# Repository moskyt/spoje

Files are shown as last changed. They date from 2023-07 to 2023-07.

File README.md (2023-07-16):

# Spoje

## Hardware

### Napajeni

vsechna ctyri napeti maji svoji indikaci na prednim panelu a svuj vypinac

na vstupnich 230VAC je pojistka

POZOR! IEC konektor na vstupu nema standardizovane zapojeni, resp. ruzne kabely jsou ruzne. je tedy treba mit na pameti, ze L a N mohou byt prohozene (a nikdo s tim nic neudela)

### DC

Meanwell RD-35B (+5/+24V)

5V napaji arduino

24V napaji telefonni linku

### Trafo

pouziva se pro vyzvaneci AC

je to trafo 400->110, tedy 230->63 voltu, coz je optimalni

### Zapojeni

viz `spoje_pcb` -- projekt v kicadu

v 'doc/` je vyexportovane schema a PCB v kicadu

vsechny draty jsou popsane

## Ovladani

### Vypinace

napajeni ctyr napeti (master 230VAC, vyzvaneci trafo, dva vystupy z DC zdroje)

cervene reset tlacitko (hardware reset na RESET pinu)

### Zvoneni

zluta tlacitka jsou na vyzvaneni na prislusnych linkach. je to SW zvoneni, aktivace stavu POKE.

## Literatura

specifikace vyzvanecich tonu:

https://www.ctu.cz/sites/default/files/obsah/clanky/navrh-sitoveho-planu-signalizace-verejnych-telekomunikacnich-siti-poskytujicich-verejne-dostupnou/soubory/priloha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

https://vyvoj.hw.cz/navrh-obvodu/rozhrani/telefonni-linky-v-cr-a-sr.html

https://www.ranecommercial.com/legacy/note150.html

http://home.zcu.cz/~vargaj/U%20S%20T/Telefonni%20pristroje.pdf

http://mcu.cz/news.php?extend.8
http://mcu.cz/images/newspost_images/00/26/00-26.pdf

https://forum.arduino.cc/t/intercom-using-two-old-dial-telephones/606457

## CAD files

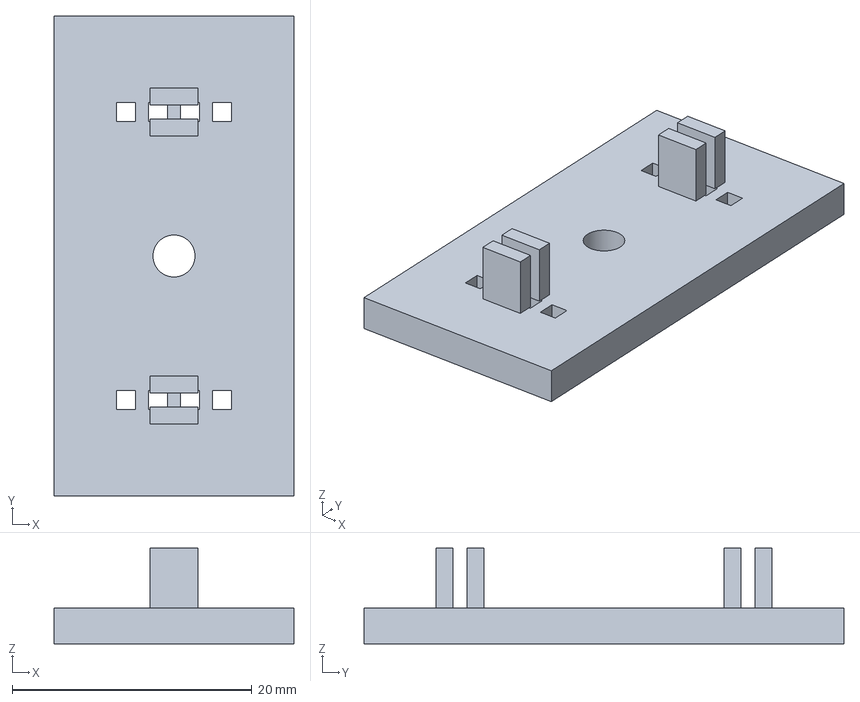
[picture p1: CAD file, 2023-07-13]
3d/neopixel_mount.3mf
20.0 x 40.0 x 8.00 mm

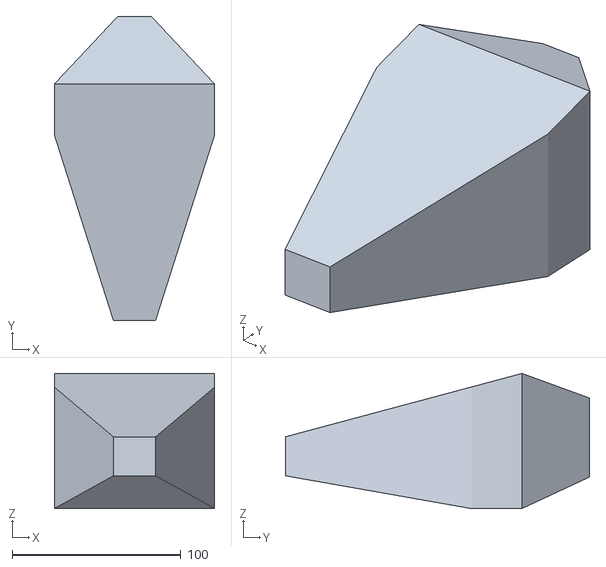
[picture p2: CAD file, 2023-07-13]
grafika/brean.stl
95.0 x 180.0 x 80.0

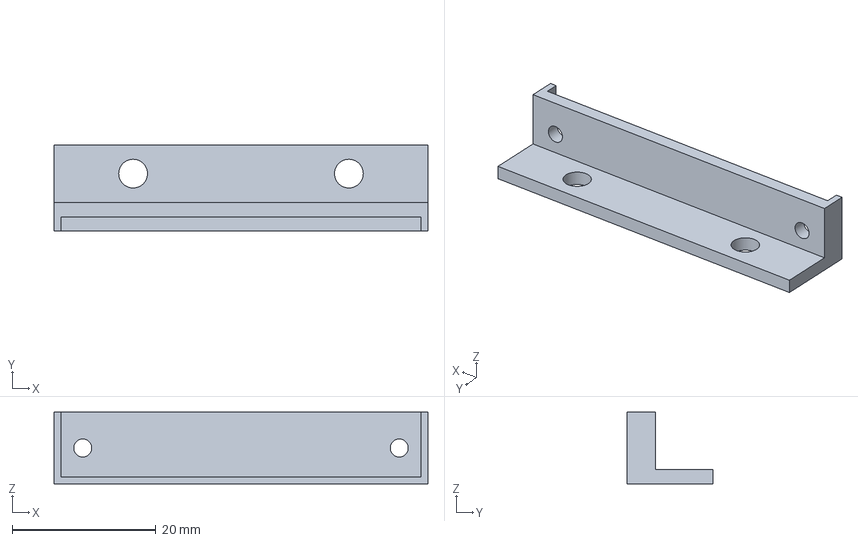
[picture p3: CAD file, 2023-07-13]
3d/relay_mount.3mf
52.0 x 12.0 x 10.0 mm

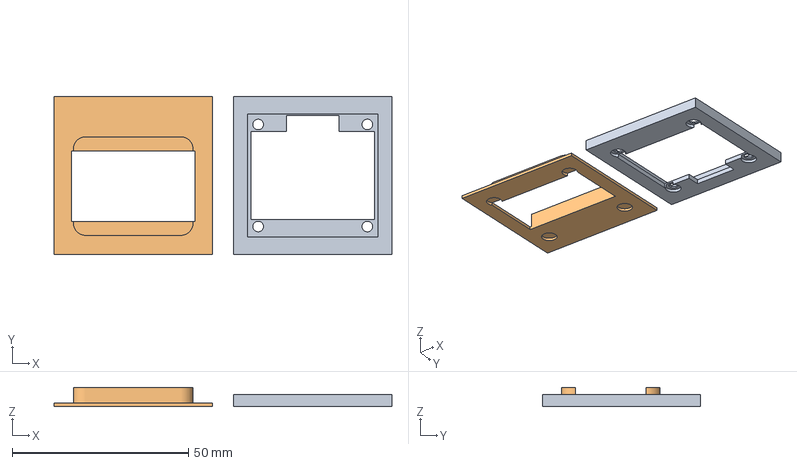
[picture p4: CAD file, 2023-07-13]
3d/oled_mount.3mf
96.0 x 45.0 x 5.50 mm
oled_mount.stl_1
oled_mount.stl_2

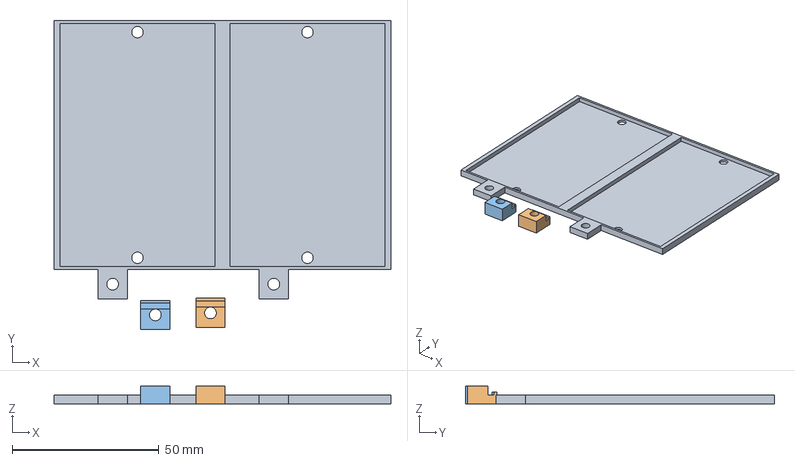
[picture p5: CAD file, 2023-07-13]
3d/boards_base.3mf
115.0 x 105.5 x 6.00 mm
boards_base.stl_1
boards_base.stl_2
boards_base.stl_3

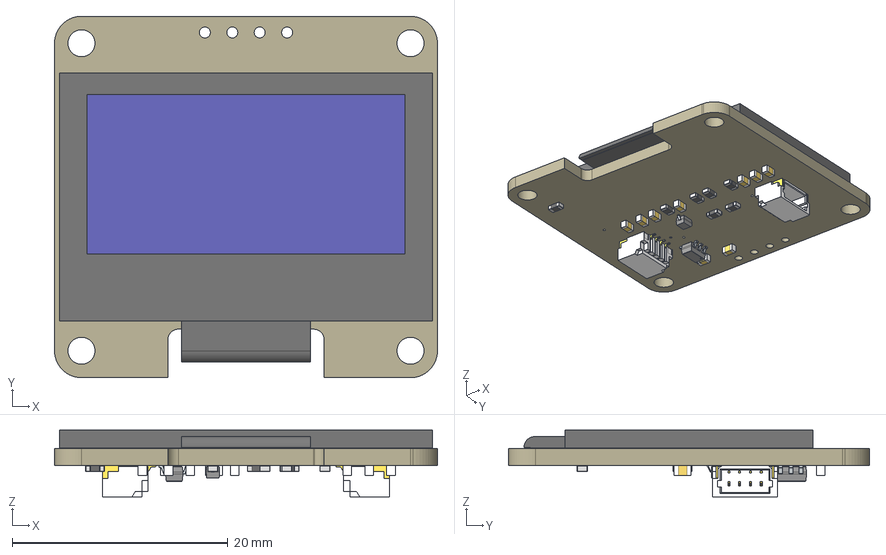
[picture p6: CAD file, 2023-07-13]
3d/OLED_1_3INCH_I2C.step
35.5 x 33.5 x 6.19 mm
Board
LASKAKIT_HEART_4MM
LASKKIT_10MM_SILKSCREEN
PinsArrayL
PinsArrayR
FilletPinL
FilletPinR
USUP_4MM_SILKSCREEN x 2
1X04_1MM_RA x 2
2,5-PAD x 4
C0603 x 9
R0603 x 7

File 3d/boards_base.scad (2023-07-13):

include <bosl2/std.scad>
$fn = 80;

eps = 0.01;


hole_spacing = 77;
board_x = 53;
board_spacing = 10;
board_y = 83;
board_z = 2;

hole_d = 3.9;

base_x = 115;
base_y = 85;
base_z = board_z + 1;

difference() {
    cuboid([base_x, base_y, base_z], anchor = TOP);
    
    up(eps)
    xcopies(board_spacing/2 + board_x, 2) {
        cuboid([board_x, board_y, board_z], anchor = TOP);
        ycopies(hole_spacing, 2)
        zcyl(d = hole_d, l = base_z+2*eps, anchor = TOP);
    }
}

fwd(base_y/2)
left(base_x/2) {
    right(20) {
        difference() {
            cuboid([10, 10, base_z], anchor = TOP+BACK);
            fwd(5) up(eps)
            zcyl(d = 4, l = base_z+2*eps, anchor = TOP);
        }
    }
    right(75) {
        difference() {
            cuboid([10, 10, base_z], anchor = TOP+BACK);
            fwd(5) up(eps)
            zcyl(d = 4, l = base_z+2*eps, anchor = TOP);
        }
    }
}


    right(100) {
        xcopies(20, 2)
        difference() {
            union() {
                cuboid([10, 10, 5], anchor = TOP+BACK);
                up(1)
                cuboid([10, 1, 5], anchor = TOP+BACK);
                fwd(3.75)
                up(5)
                cuboid([10, 6.25, 5], anchor = TOP+BACK);
            }
            fwd(5) up(eps)
            zcyl(d = 3.9, l = 100);
        }
    }

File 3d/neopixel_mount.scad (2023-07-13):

include <bosl2/std.scad>
$fn = 80;

eps = 0.01;

spacing = 24;

block_x = 20;
block_y = 40;
slit_x = 8;
slit_y = 0.8;
support_z = 5;

inner_z = 3;
outer_z = 3;

spacer_d = 10;

left(40)
difference() {
    cuboid([block_x, block_y, outer_z], anchor = BOTTOM);
    
    down(eps)
    ycopies(n = 2, l = spacing) 
    zcyl(l=100, d=spacer_d);
    
    zcyl(l=100, d=3.5);
    up(outer_z/2)
    zcyl(l=100, d=6, anchor = BOTTOM);
}

difference() {
    union() {
        cuboid([block_x, block_y, inner_z], anchor = BOTTOM);
        
        ycopies(n = 2, l = spacing) 
        up(inner_z)
        cuboid([slit_x/2, slit_x/2, support_z], anchor = BOTTOM);
    }
    
    ycopies(n = 2, l = spacing) {
        up(inner_z)
        cuboid([slit_x, slit_y*1.5, support_z+2*eps], anchor = BOTTOM);
        
        down(eps)
        xcopies(n = 4, l = slit_x) 
        cuboid([slit_y*2, slit_y*2, inner_z+2*eps], anchor = BOTTOM);
    }
    
    zcyl(l=100, d=3.5);
}

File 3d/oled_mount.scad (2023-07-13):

include <bosl2/std.scad>
$fn = 80;

eps = 0.01;

window_x = 34;
window_y = 28;
glass_x = 35;
glass_y = 25;
view_x = 35;
view_y = 20;
mount_x = 45;
mount_y = 45;
board_x = 37;
board_y = 35;

outer_z = 1.5;
inner_z = 2;

cover_z = 1;    
shift_window = 3;

back(100) 
union() {
difference() {
    cuboid([mount_x, mount_y, cover_z], anchor = BOTTOM);

    down(eps)
    back(shift_window)
    cuboid([view_x, view_y, cover_z+2*eps], anchor = BOTTOM);

    up(0.1)
    xcopies(n=2, l=31)
    ycopies(n=2, l=29)
    zcyl(d = 5, l = cover_z+2*eps, anchor=BOTTOM);

}
    back(shift_window) difference() {
        cuboid([window_x, window_y, 4.5], anchor = TOP, edges="Z", rounding=3.5);
        up(eps)
        cuboid([view_x, view_y, 4.5+2*eps], anchor = TOP);
    }

}

difference() {
    cuboid([mount_x, mount_y, outer_z+inner_z], anchor = BOTTOM);
    down(eps)
    cuboid([glass_x, glass_y, outer_z+inner_z+2*eps], anchor = BOTTOM);
    up(outer_z)
    cuboid([board_x, board_y, inner_z+2*eps], anchor = BOTTOM);

    down(eps)
    xcopies(n=2, l=31)
    ycopies(n=2, l=29)
    zcyl(d = 3, l = 8, anchor=BOTTOM);

    down(eps)
    xcopies(n=2, l=31)
    ycopies(n=2, l=29)
    zcyl(d = 5, l = outer_z-0.5, anchor=BOTTOM);
 
    down(eps)
    back(12)
    cuboid([15, 5, 100+2*eps], anchor = BOTTOM+FWD);
   
}

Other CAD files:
3d/relay_mount.scad
3d/boards_base.stl
3d/neopixel_mount.stl
3d/oled_mount.stl
3d/relay_mount.stl

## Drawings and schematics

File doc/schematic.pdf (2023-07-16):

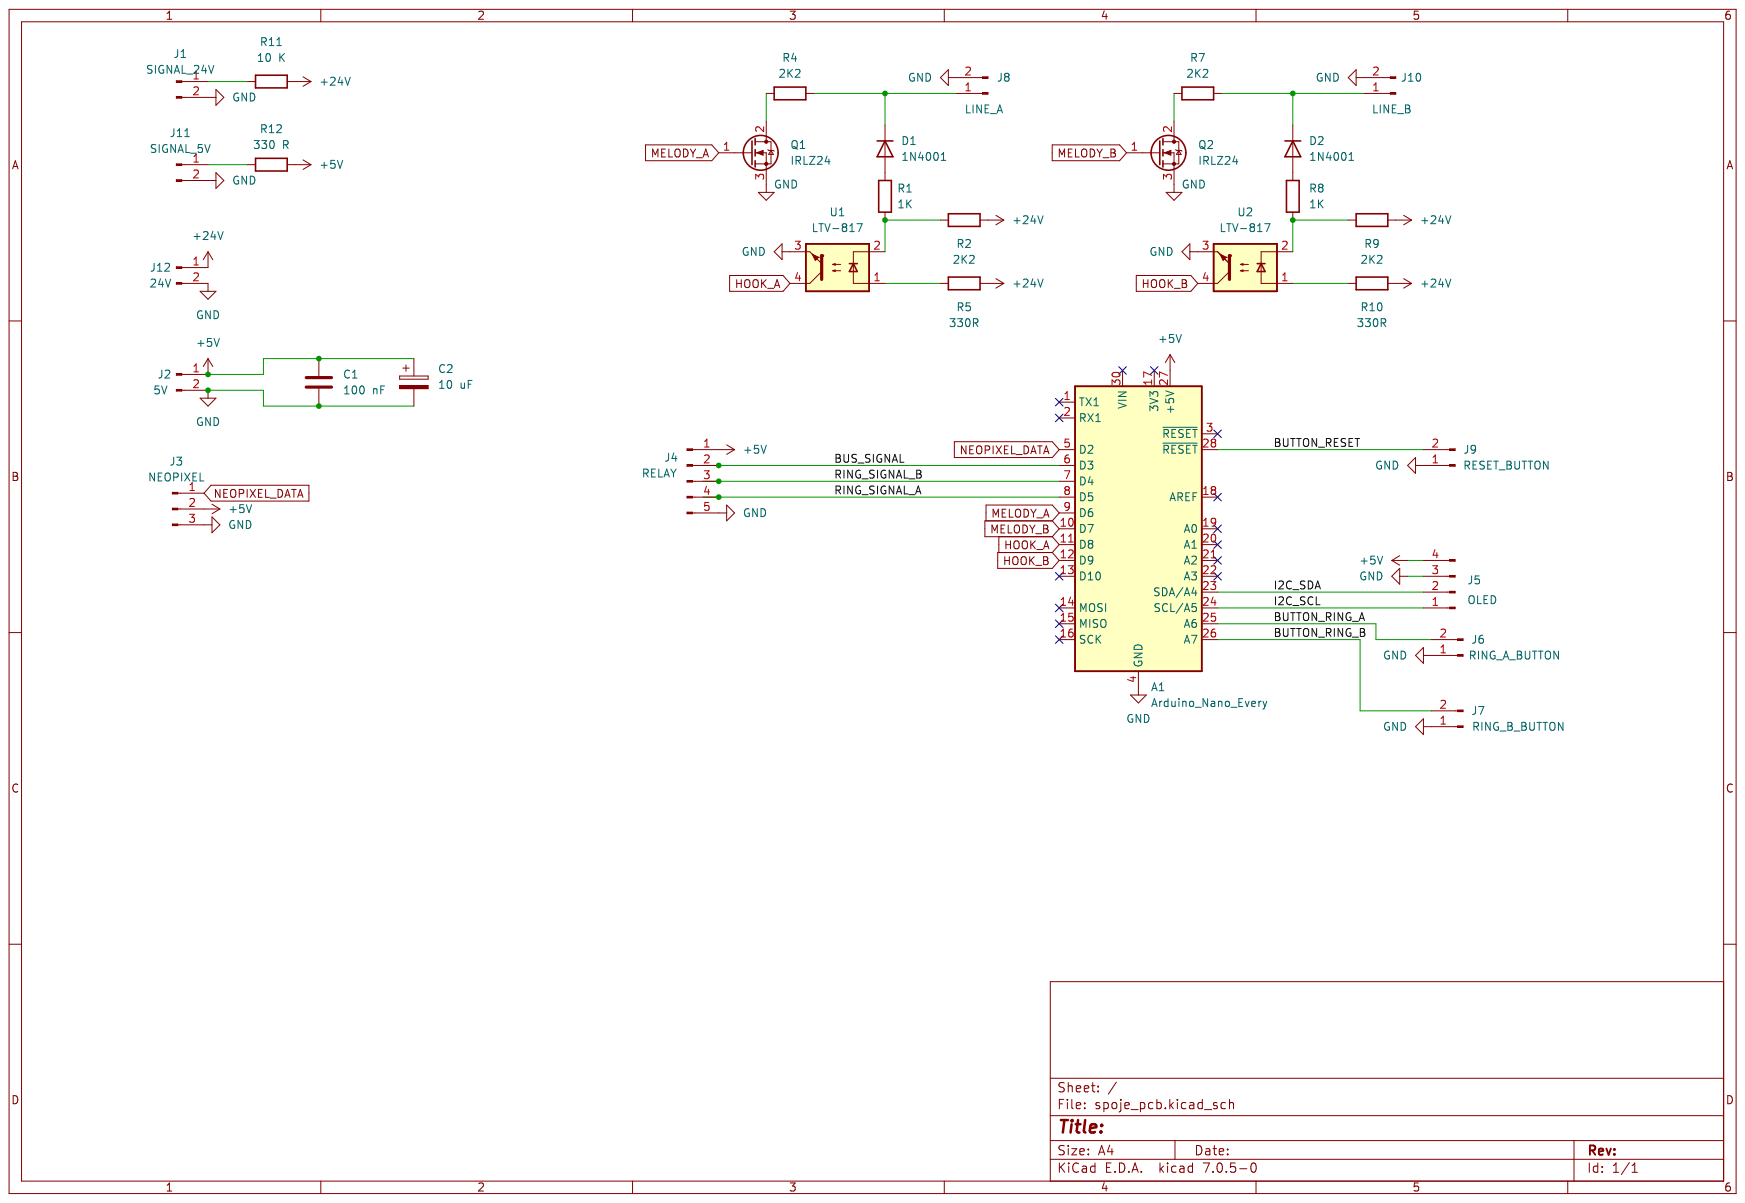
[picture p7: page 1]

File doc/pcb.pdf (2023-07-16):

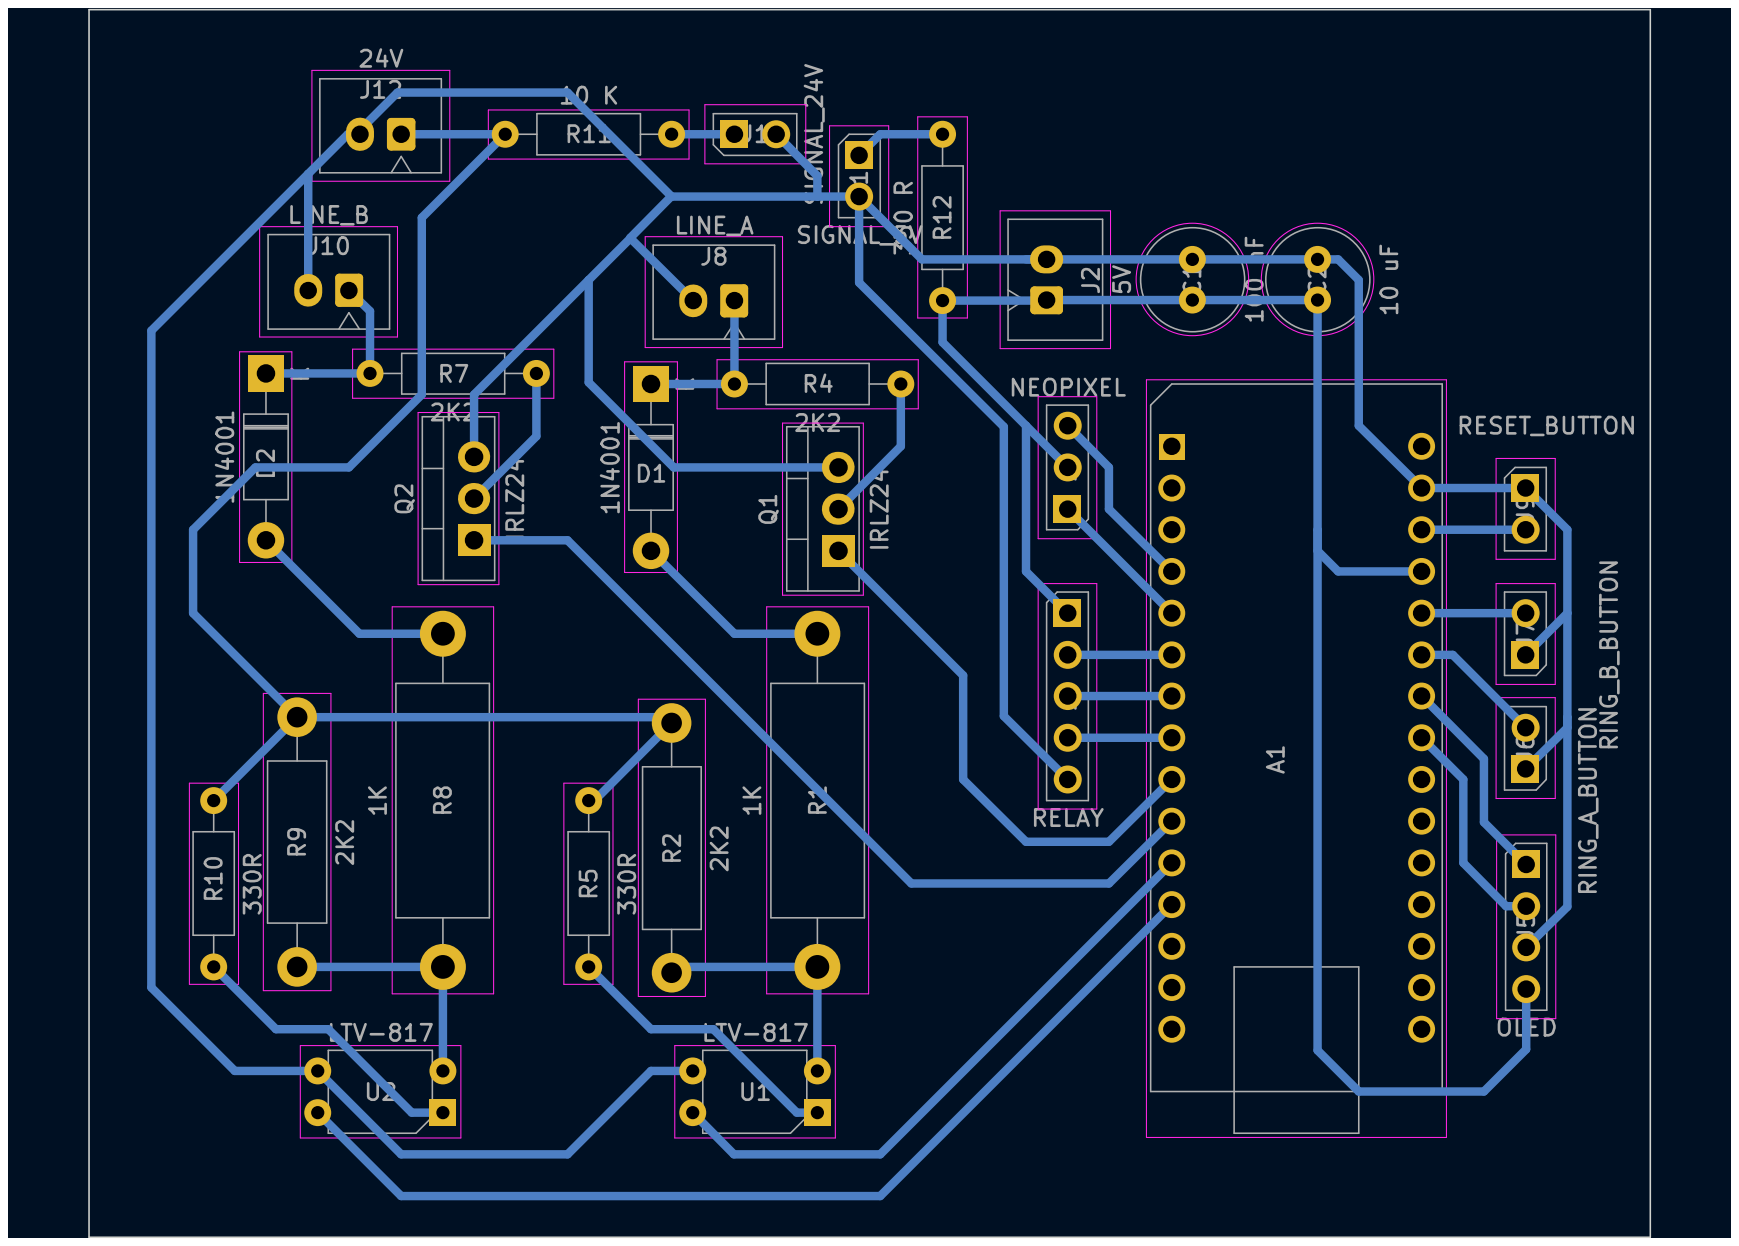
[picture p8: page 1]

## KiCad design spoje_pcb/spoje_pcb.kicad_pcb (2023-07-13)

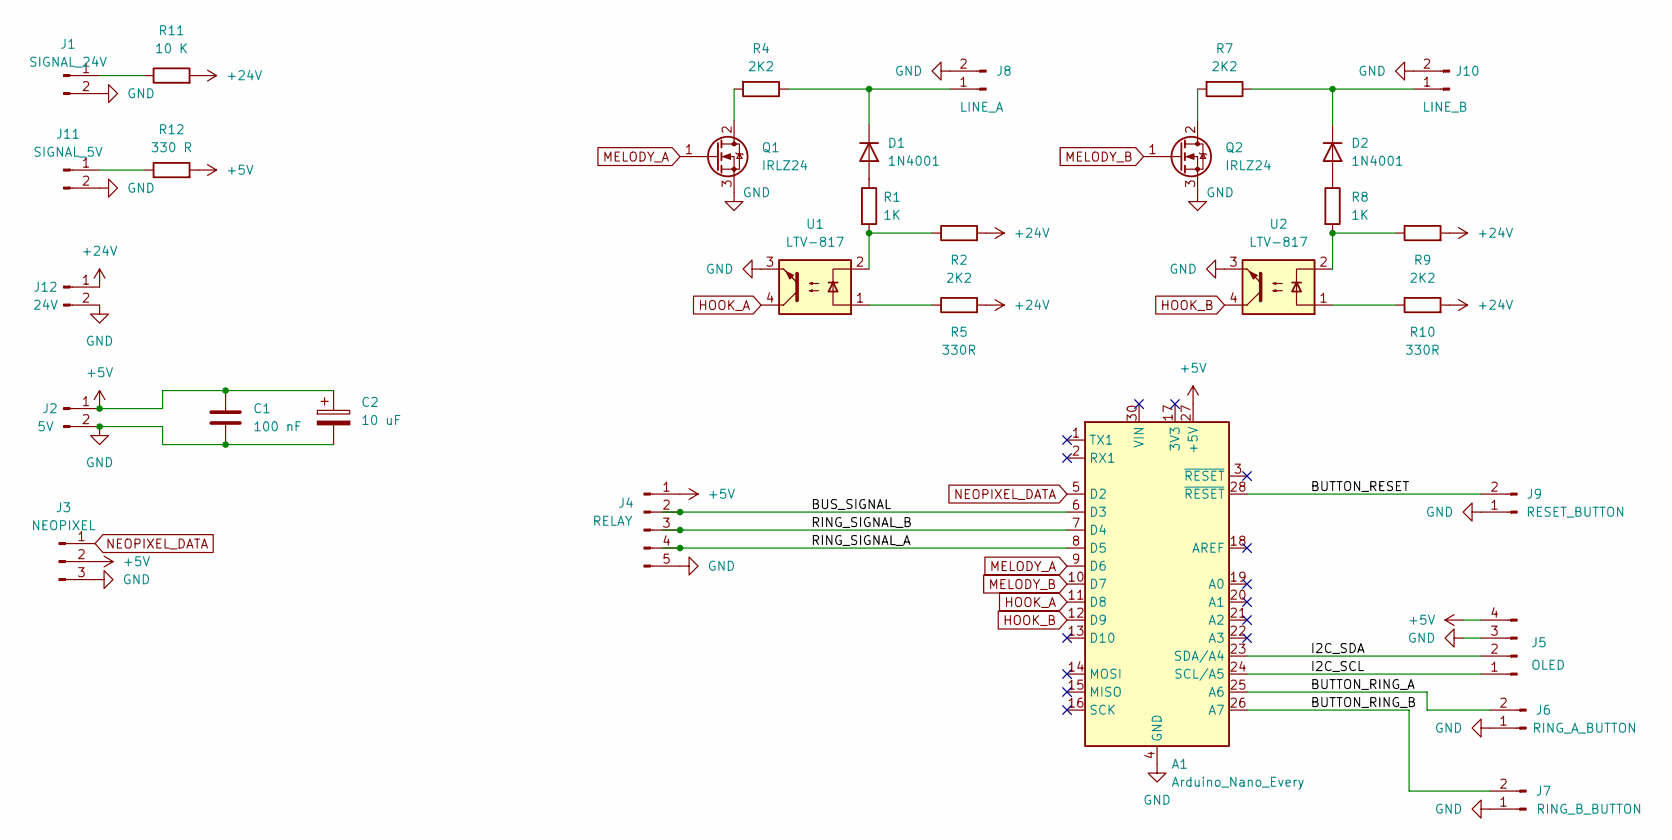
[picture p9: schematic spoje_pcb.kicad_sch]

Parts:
A1: Arduino_Nano_Every; Arduino_Nano
C1: 100 nF; C_Radial_D6.3mm_H5.0mm_P2.50mm
C2: 10 uF; C_Radial_D6.3mm_H5.0mm_P2.50mm
D1, D2: 1N4001; D_DO-41_SOD81_P10.16mm_Horizontal
J1: SIGNAL_24V; PinHeader_1x02_P2.54mm_Vertical
J2: 5V; JST_XH_B2B-XH-A_1x02_P2.50mm_Vertical
J3: NEOPIXEL; PinHeader_1x03_P2.54mm_Vertical
J4: RELAY; PinHeader_1x05_P2.54mm_Vertical
J5: OLED; PinHeader_1x04_P2.54mm_Vertical
J6: RING_A_BUTTON; PinHeader_1x02_P2.54mm_Vertical
J7: RING_B_BUTTON; PinHeader_1x02_P2.54mm_Vertical
J8: LINE_A; JST_XH_B2B-XH-A_1x02_P2.50mm_Vertical
J9: RESET_BUTTON; PinHeader_1x02_P2.54mm_Vertical
J10: LINE_B; JST_XH_B2B-XH-A_1x02_P2.50mm_Vertical
J11: SIGNAL_5V; PinHeader_1x02_P2.54mm_Vertical
J12: 24V; JST_XH_B2B-XH-A_1x02_P2.50mm_Vertical
Q1, Q2: IRLZ24; TO-220-3_Vertical
R1, R8: 1K; R_Axial_DIN0614_L14.3mm_D5.7mm_P20.32mm_Horizontal
R2, R9: 2K2; R_Axial_DIN0411_L9.9mm_D3.6mm_P15.24mm_Horizontal
R4, R7: 2K2; R_Axial_DIN0207_L6.3mm_D2.5mm_P10.16mm_Horizontal
R5, R10: 330R; R_Axial_DIN0207_L6.3mm_D2.5mm_P10.16mm_Horizontal
R11: 10 K; R_Axial_DIN0207_L6.3mm_D2.5mm_P10.16mm_Horizontal
R12: 330 R; R_Axial_DIN0207_L6.3mm_D2.5mm_P10.16mm_Horizontal
U1, U2: LTV-817; DIP-4_W7.62mm

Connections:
+5V: A1.27 (+5V), C1.1, C2.1, J2.1, J3.2, J4.1, J5.4, R12.2
+24V: J12.1, R2.2, R5.2, R9.2, R10.2, R11.2
/BUS_SIGNAL: A1.6 (D3), J4.2
/BUTTON_RESET: A1.28 (~RESET), J9.2
/BUTTON_RING_A: A1.25 (A6), J6.2
/BUTTON_RING_B: A1.26 (A7), J7.2
/I2C_SCL: A1.24 (SCL/A5), J5.1
/I2C_SDA: A1.23 (SDA/A4), J5.2
/RING_SIGNAL_A: A1.7 (D4), J4.3
/RING_SIGNAL_B: A1.8 (D5), J4.4
GND: A1.4 (GND), A1.29 (GND), C1.2, C2.2, J1.2, J2.2, J3.3, J4.5, J5.3, J6.1, J7.1, J8.2, J9.1, J10.2, J11.2, J12.2, Q1.3 (S), Q2.3 (S), U1.3, U2.3
HOOK_A: A1.11 (D8), U1.4
HOOK_B: A1.12 (D9), U2.4
MELODY_A: A1.9 (D6), Q1.1 (G)
MELODY_B: A1.10 (D7), Q2.1 (G)
NEOPIXEL_DATA: A1.5 (D2), J3.1
unnamed: D1.2 (A), R1.1
unnamed: D1.1 (K), J8.1, R4.1
unnamed: D2.2 (A), R8.1
unnamed: D2.1 (K), J10.1, R7.1
unnamed: J1.1, R11.1
unnamed: J11.1, R12.1
unnamed: Q1.2 (D), R4.2
unnamed: Q2.2 (D), R7.2
unnamed: R1.2, R2.1, U1.2
unnamed: R5.1, U1.1
unnamed: R8.2, R9.1, U2.2
unnamed: R10.1, U2.1

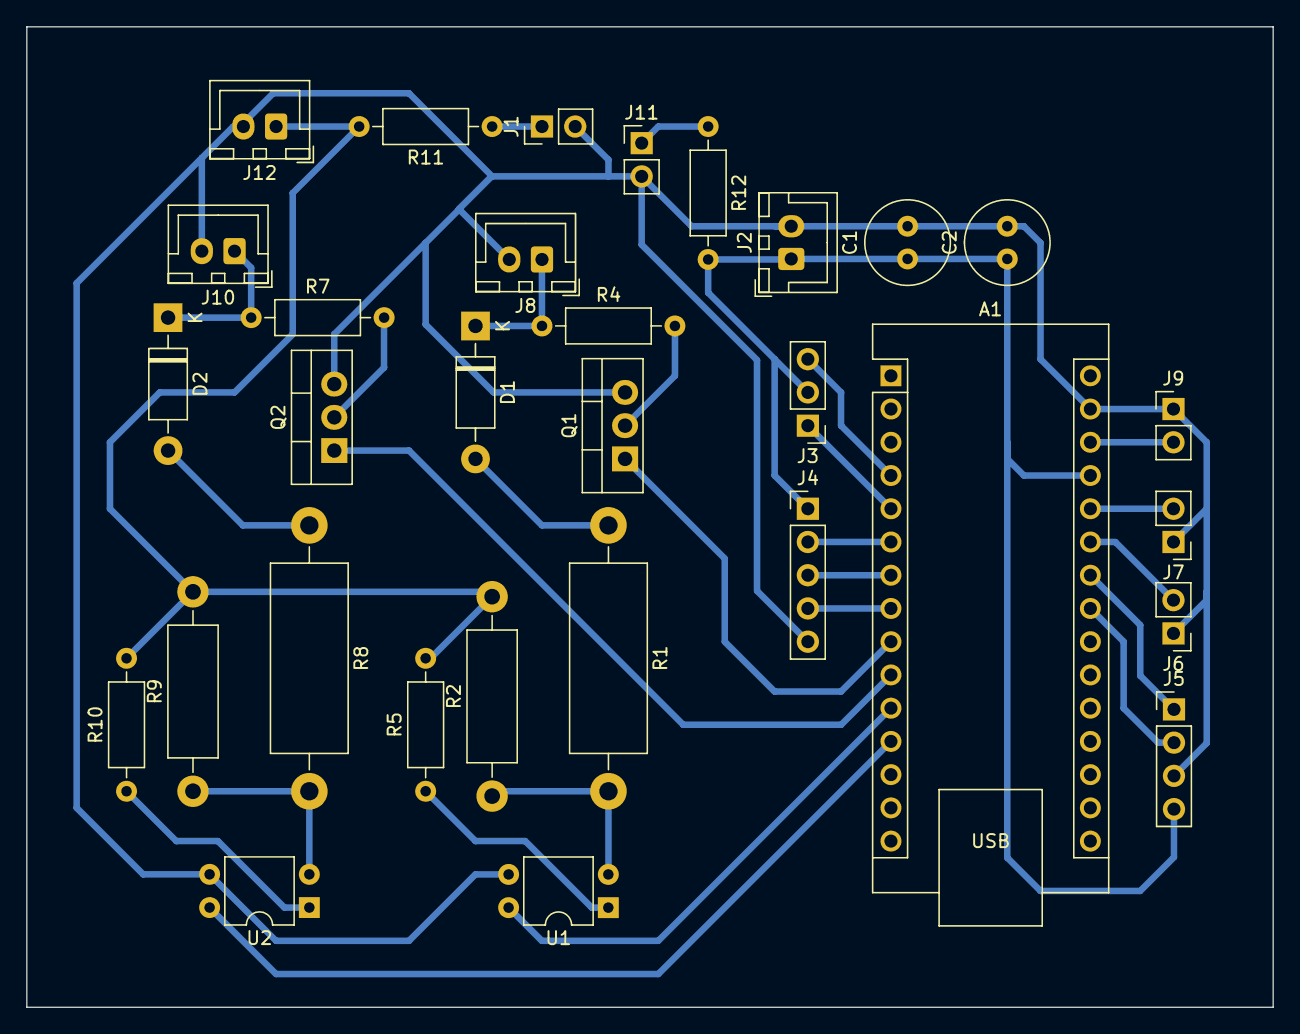
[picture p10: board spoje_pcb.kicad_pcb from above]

Board: 2 copper layers, 95.2 x 74.9 mm, 31 parts (0 on the bottom side), 28 nets.

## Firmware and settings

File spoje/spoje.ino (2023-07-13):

// #include "pcf8574.h" // pcf8574 library, 1.0.3
#include <Wire.h>
// #include <Adafruit_GFX.h> // Adafruit GFX library, 1.11.5
// #include <Adafruit_SH110X.h> // Adafruit SH110X library, 2.1.8
#include <Adafruit_NeoPixel.h> // Adafruit NeoPixel library, 1.11.0
#include <Toggle.h> // Toggle library, 3.1.8
#include <U8g2lib.h> // U8g2@2.33.15

const int PHONE_NUMBER_A = 111;
const int PHONE_NUMBER_B = 222;

//--- pins and adresses

const int PIN_HOOK_A = 8;
const int PIN_HOOK_B = 9;
const int PIN_NEOPIXEL = 2;
const int PIN_TONE_A = 6;
const int PIN_TONE_B = 7;
const int PIN_RING_A = 5;
const int PIN_RING_B = 4;
const int PIN_BUS = 3;
const int PIN_BUTTON_A = 20;
const int PIN_BUTTON_B = 21;

const int I2C_OLED = 0x3C;

//--- hardware

//Adafruit_SH1106G display(128, 64, &Wire, -1);
U8G2_SH1106_128X64_NONAME_1_HW_I2C display(U8G2_R0, U8X8_PIN_NONE);
U8G2LOG log_display;
#define U8LOG_WIDTH 25
#define U8LOG_HEIGHT 8
uint8_t log_buffer[U8LOG_WIDTH*U8LOG_HEIGHT];

Adafruit_NeoPixel pixels(2, PIN_NEOPIXEL, NEO_RGB + NEO_KHZ800);

// timers stuff -- taken from the library

// Select USING_16MHZ     == true for  16MHz to Timer TCBx => shorter timer, but better accuracy
// Select USING_8MHZ      == true for   8MHz to Timer TCBx => shorter timer, but better accuracy
// Select USING_250KHZ    == true for 250KHz to Timer TCBx => shorter timer, but better accuracy
// Not select for default 250KHz to Timer TCBx => longer timer,  but worse accuracy
#define USING_16MHZ     false
#define USING_8MHZ      false
#define USING_250KHZ    false

// Select the timers you're using
// Cannot use TIMER_1 as it conflicts with tone
// TIMER_3 also conflicts with something
#define USE_TIMER_0     false
#define USE_TIMER_1     false
#define USE_TIMER_2     true
#define USE_TIMER_3     false

#include "megaAVR_TimerInterrupt.h"
#include "megaAVR_ISR_Timer.h" 

ISR_Timer ISR_Timer2;
int timer_dial = -1;
int timer_ring = -1;
int timer_melody = -1;

// --- line modes
enum lineMode {
  MODE_NULL, // this is only for the 'new_mode', meaning no change
  MODE_IDLE, // no ringing, on hook
  MODE_WAIT, // off hook, but not dialing (play Dial melody)
  MODE_DIAL, // dialing in progress (no melody here)
  MODE_INVALID, // failed call, invalid number (play Invalid melody)
  MODE_BUSY, // failed call, other is busy (play Busy melody)
  MODE_CALL, // successful call, waiting for the other to pick up (play Ring melody)
  MODE_RING, // ringing
  MODE_CONNECT, // connected to the bus
  MODE_POKE, // quick ring notification
  MODE_MUTE // picked up but the other one is already active, so "play dead"
};

// --- lines
enum lineID { LINE_A, LINE_B };

volatile lineMode mode_A = MODE_IDLE;
volatile lineMode mode_B = MODE_IDLE;

volatile bool hw_ring_A = false;
volatile bool hw_ring_B = false;

// --- dial stuff --- this is ofcourse stupid, needs to be twice => class
// timer/counter
volatile int dialCount = 0;
// current number being read
volatile int dialBuffer = 0;
// number of digits in code
const int dialNMax = 3;
// current code read
volatile int dialNumber[dialNMax] = {0,0,0};
// current digit
volatile int dialPtr = 0;
//
volatile int dial_read = -1;
//
volatile int currentDialPin = -1;
//
volatile bool dialHangupFlag = false;
//
volatile bool dialStartedFlag = false;
//
volatile bool dialPrimerFlag = false;

// --- melodies: tone-duration pairs. last tone has to be 0.
// unit in CTU specs is 165 ms, we have 150 
const int melodyDialLength_ = 4;
unsigned short int melodyDial_[2*melodyDialLength_] = {1,2,0,2,1,4,0,4};
const int melodyCallLength_ = 2;
unsigned short int melodyCall_[2*melodyCallLength_] = {1,6,0,24};
const int melodyInvalidLength_ = 4;
unsigned short int melodyInvalid_[2*melodyInvalidLength_] = {2,2,3,2,4,2,0,10};
const int melodyBusyLength_ = 2;
unsigned short int melodyBusy_[2*melodyBusyLength_] = {1,2,0,2};
const int melodyFailedLength_ = 2;
unsigned short int melodyFailed_[2*melodyFailedLength_] = {1,1,0,1};

// length of current melody (in melodyBuffer)
int melodyLength = 0;
// pointer to current note in melodyBuffer
int melodyPointer = 0;
// pin on which the melody is played
int melodyPin = 0;
// current melody buffer (expanded melody vector)
int melodyBuffer[100];

// count cycles where both lines are idle
int idleCounter = 0;
// at this count system goes to sleep
const int idleThreshold = 1000;
// sleep flag
bool sleep = false;

// handle for the slow ISR interrrupts (ring and melody)
void Timer2Handler() {
  ISR_Timer2.run();
}

// this is kinda melodyPonter
volatile int ringCounter = 0;

void RingHandler() {
  if ((mode_A == MODE_RING) || (mode_B == MODE_RING)) {
    // this looks like a good pattern:
    // ---.---.....
    if (
        (ringCounter >= 0 && ringCounter < 3 ) ||
        (ringCounter >= 4 && ringCounter < 7 )
      ) {
      if (mode_A == MODE_RING) hw_ring_A = true;
      if (mode_B == MODE_RING) hw_ring_B = true;
    } else {
      hw_ring_A = false;
      hw_ring_B = false;
    }
    ringCounter++;
    if (ringCounter >= 12) ringCounter = 0;
  } else if ((mode_A == MODE_POKE) || (mode_B == MODE_POKE)) {
    if (
        (ringCounter >=  0 && ringCounter <  2 ) ||
        (ringCounter >=  4 && ringCounter <  6 ) ||
        (ringCounter >=  8 && ringCounter < 10 ) ||
        (ringCounter >= 12 && ringCounter < 14 ) ||
        (ringCounter >= 16 && ringCounter < 18 )
      ) {
      if (mode_A == MODE_POKE) hw_ring_A = true;
      if (mode_B == MODE_POKE) hw_ring_B = true;
    } else {
      hw_ring_A = false;
      hw_ring_B = false;
    }
    ringCounter++;
    if (ringCounter >= 20) {
      ringCounter = 0;
      if (mode_A == MODE_POKE) {
        Serial.println("A => IDLE");
        mode_A = MODE_IDLE;
      }
      if (mode_B == MODE_POKE) {
        Serial.println("B => IDLE");
        mode_B = MODE_IDLE;
      }
    }
  } else {
    hw_ring_A = false;
    hw_ring_B = false;
    ringCounter = 0;
  }
}

// byte hook_A_ = LOW;
// byte hook_B_ = LOW;
volatile Toggle hook_A(PIN_HOOK_A);
volatile Toggle hook_B(PIN_HOOK_B);
Toggle *dialer = NULL;

Toggle ring_button_A(PIN_BUTTON_A);
Toggle ring_button_B(PIN_BUTTON_B);

const int hook_state_threshold = 100;
const int hook_pickup_threshold = 150;
//const int hook_state_threshold = 500;
//const int hook_pickup_threshold = 750;
bool off_hook_A = false;
bool off_hook_B = false;

void setStatus(lineMode mode, int pixel_index) {
  if (mode == MODE_IDLE)
    pixels.setPixelColor(pixel_index, 10, 10, 10);
  else if (mode == MODE_WAIT)
    pixels.setPixelColor(pixel_index,  0, 50,  0);
  else if (mode == MODE_DIAL)
    pixels.setPixelColor(pixel_index,  0, 90,  0);
  else if (mode == MODE_INVALID)
    pixels.setPixelColor(pixel_index, 50, 50,  0);
  else if (mode == MODE_BUSY)
    pixels.setPixelColor(pixel_index, 50, 20,  0);
  else if (mode == MODE_CALL)
    pixels.setPixelColor(pixel_index,  0, 50, 50);
  else if (mode == MODE_RING)
    pixels.setPixelColor(pixel_index, 50,  0, 50);
  else if (mode == MODE_POKE)
    pixels.setPixelColor(pixel_index,250,  0,250);
  else if (mode == MODE_CONNECT)
    pixels.setPixelColor(pixel_index,  0,  0, 50);
  else
    pixels.setPixelColor(pixel_index,  1,  1,  1);
}

void loop() {

  if (currentDialPin == PIN_HOOK_A) {
    if (dialHangupFlag) {
      stopMelody();
      off_hook_A = false; 
      currentDialPin = -1;
      ISR_Timer2.disable(timer_dial);
      hook_A.clearTimer();
      hook_A.poll();
    } else {
      off_hook_A = true;
    }
  } else {
    hook_A.poll();

    if (hook_A.releasedFor(hook_pickup_threshold)) off_hook_A = true;
    if (hook_A.pressedFor(hook_state_threshold))  off_hook_A = false;
  }

  if (currentDialPin == PIN_HOOK_B) {
    if (dialHangupFlag) {
      stopMelody();
      off_hook_B = false; 
      currentDialPin = -1;
      ISR_Timer2.disable(timer_dial);
      hook_B.clearTimer();
      hook_B.poll();
    } else {
      off_hook_B = true;
    }
  } else {
    hook_B.poll();

    if (hook_B.releasedFor(hook_pickup_threshold)) off_hook_B = true;
    if (hook_B.pressedFor(hook_state_threshold))  off_hook_B = false;
  }

  if (hw_ring_A) off_hook_A = false;
  if (hw_ring_B) off_hook_B = false;

  unsigned long now = millis();
  
  // Serial.print(off_hook_A);
  // Serial.print(off_hook_B);
  // Serial.print("-");
  // Serial.print(digitalRead(PIN_HOOK_A));
  // Serial.println(digitalRead(PIN_HOOK_B));

  {
    lineMode new_mode = updateState(LINE_A, mode_A, off_hook_A, 'A', mode_B);  
    if (new_mode != MODE_NULL) {
      mode_A = new_mode;
      if (new_mode == MODE_WAIT) {
        log_display.println("A zvednul sluchatko");
      }
      setNewState(LINE_A, new_mode, 'A');
    }
    if (new_mode == MODE_WAIT) {
      currentDialPin = PIN_HOOK_A;
      dialCount = 0;
      dialHangupFlag = false;
      dialStartedFlag = false;
      dialPrimerFlag = false;
      dialer = &hook_A;
      digitalWrite(PIN_TONE_A, LOW);
      dialer->poll();
      delay(1);
      ISR_Timer2.enable(timer_dial);
    }
    if (new_mode == MODE_DIAL) {
      stopMelody();
    }
  }
  {
    lineMode new_mode = updateState(LINE_B, mode_B, off_hook_B, 'B', mode_A);  
    if (new_mode != MODE_NULL) {
      mode_B = new_mode;
      if (new_mode == MODE_WAIT) {
        log_display.println("B zvednul sluchatko");
      }
      setNewState(LINE_B, new_mode, 'B');
    }
    if (new_mode == MODE_WAIT) {
      currentDialPin = PIN_HOOK_B;
      dialCount = 0;
      dialHangupFlag = false;
      dialStartedFlag = false;
      dialPrimerFlag = false;
      dialer = &hook_B;
      pinMode(currentDialPin, INPUT_PULLUP);
      digitalWrite(PIN_TONE_B, LOW);
      dialer->poll();
      delay(1);
      ISR_Timer2.enable(timer_dial);
    }
    if (new_mode == MODE_DIAL) {
      stopMelody();
    }
  }

  ring_button_A.poll();
  ring_button_B.poll();
  if ((mode_A == MODE_IDLE) && (mode_B == MODE_IDLE)) {
    if (ring_button_A.onPress()) {
      Serial.println(F("A ~ POKE"));
      mode_A = MODE_POKE;
    }
    if (ring_button_B.onPress()) {
      Serial.println(F("B ~ POKE"));
      mode_B = MODE_POKE;
    }
  }

  // -- did someone finish dialing?
  if (dial_read >= 0) {
    currentDialPin = 0;
    ISR_Timer2.disable(timer_dial);

    if (mode_A == MODE_DIAL) 
      mode_A = processDial(LINE_A, 'A', 'B', PHONE_NUMBER_B);
    if (mode_B == MODE_DIAL) 
      mode_B = processDial(LINE_B, 'B', 'A', PHONE_NUMBER_A);

    dial_read = -1;
  }

  // -- now either ring or switch to busy
  executeRing(LINE_A, LINE_B, mode_A, mode_B, 'A', 'B');
  executeRing(LINE_B, LINE_A, mode_B, mode_A, 'B', 'A');


  // -- AWFUL HACK! lets disable it for a while it might make things baad
  // if (mode_A == MODE_WAIT && mode_B == MODE_IDLE) melodyPin = PIN_TONE_A;
  //if (mode_B == MODE_WAIT && mode_A == MODE_IDLE) melodyPin = PIN_TONE_B;

  // -- connect
  if ((mode_A == MODE_CONNECT && mode_B == MODE_CALL) || (mode_A == MODE_CALL && mode_B == MODE_CONNECT)) {
    Serial.println("Connecting!");
    log_display.println("Spojuji hovor");

    stopMelody();
    currentDialPin = 0;
    ISR_Timer2.disable(timer_dial);
    setNewState(LINE_A, MODE_CONNECT, 'A');
    setNewState(LINE_B, MODE_CONNECT, 'B');
    mode_A = MODE_CONNECT;    
    mode_B = MODE_CONNECT;    
  }

  // -- disconnect
  if (mode_A == MODE_CONNECT && mode_B != MODE_CONNECT) {
    setNewState(LINE_A, MODE_BUSY, 'A');
    mode_A = MODE_BUSY;
    currentDialPin = 0;
    ISR_Timer2.disable(timer_dial);
    dialCount = 0;
    dialPrimerFlag = false;
    dialStartedFlag = false;
    dialHangupFlag = false;
    currentDialPin = 0;
    dialer = NULL;

    log_display.println("A odpojen");
  }
  if (mode_B == MODE_CONNECT && mode_A != MODE_CONNECT) {
    setNewState(LINE_B, MODE_BUSY, 'B');
    mode_B = MODE_BUSY;
    currentDialPin = 0;
    ISR_Timer2.disable(timer_dial);
    dialCount = 0;
    dialPrimerFlag = false;
    dialStartedFlag = false;
    dialHangupFlag = false;
    currentDialPin = 0;
    dialer = NULL;

    log_display.println("B odpojen");
  }

  // -- I feel that we should do some state based cleanup. Because it's safer.
  // - kill invalid combinations. allowed are RING-CALL, CONNECT-CONNECT, DIAL-IDLE
  // TBD
  // - turn off ringer unless in ring mode
  // TBD
  // - disconnect bus unless in connected mode
  // TBD
  // - disconnect tone unless in melody-attached mode
  // TBD

  set_ringer(LINE_A, hw_ring_A);
  set_ringer(LINE_B, hw_ring_B);

  if ((mode_A == MODE_IDLE) && (mode_B == MODE_IDLE)) {
    
    idleCounter++;
    if (idleCounter > idleThreshold) {
      sleep = true;

      currentDialPin = -1;
      ISR_Timer2.disable(timer_dial);
      stopMelody();
      set_bus(false);
      set_ringer(LINE_A, false);
      set_ringer(LINE_B, false);
      display.clearDisplay();
    }
  } else {
    if (sleep) {
      // wake up!
      log_display.print("\f");
    }
    idleCounter = 0;
    sleep = false;
  }

  //! ??? 
  if (melodyPin == PIN_HOOK_A && !off_hook_A) stopMelody();
  if (melodyPin == PIN_HOOK_B && !off_hook_B) stopMelody();

  if (sleep) {
    pixels.setPixelColor(0, 1, 1, 1);
    pixels.setPixelColor(1, 1, 1, 1);
  } else {
    setStatus(mode_A, 0);
    setStatus(mode_B, 1);
  }
  pixels.show();

  delay(50);

}

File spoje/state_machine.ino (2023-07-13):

/*
  MODE_IDLE, // no ringing, on hook
  MODE_WAIT, // off hook, but not dialing (play Dial melody)
  MODE_DIAL, // dialing in progress (no melody here)
  MODE_INVALID, // failed call, invalid number (play Busy melody)
  MODE_BUSY, // failed call, other is busy (play Busy melody)
  MODE_CALL, // successful call, waiting for the other to pick up (play Ring melody)
  MODE_RING, // ringing
  MODE_CONNECT, // connected to the bus
  */

lineMode updateState(lineID line, lineMode mode, bool off_hook, char line_name, lineMode other_mode) {

  lineMode new_mode = MODE_NULL;

  // -- state machine
  if ((mode == MODE_IDLE) && off_hook && (other_mode == MODE_IDLE)) {
    Serial.print(line_name);
    Serial.println(" IDLE -> WAIT");
    //log_display.print(line_name);
    //log_display.println(" zvednul sluchatko");
    new_mode = MODE_WAIT;    
  }
  else if ((mode == MODE_IDLE) && off_hook && (other_mode != MODE_IDLE)) {
    Serial.print(line_name);
    Serial.println(" IDLE -> MUTE");
    //log_display.print(line_name);
    //log_display.println(" zvednul sluchatko");
    new_mode = MODE_MUTE;    
  }
  else if ((mode == MODE_RING) && off_hook) {
    Serial.print(line_name);
    Serial.println(" RING -> CONNECT");
    //log_display.print(line_name);
    //log_display.println(" prijal");
    new_mode = MODE_CONNECT;    
  }
  else if ((mode == MODE_WAIT) && dialStartedFlag) {
    Serial.print(line_name);
    Serial.println(" WAIT -> DIAL");
    //log_display.print(line_name);
    //log_display.println(" vytaci");
    dialPtr = 0;
    new_mode = MODE_DIAL;    
  }
  else if ((mode == MODE_DIAL) && !off_hook) {
    Serial.print(line_name);
    Serial.println(" DIAL -> IDLE");
    //log_display.print(line_name);
    //log_display.println(" zavesil");
    new_mode = MODE_IDLE;    
  }
  else if ((mode == MODE_WAIT) && !off_hook) {
    Serial.print(line_name);
    Serial.println(" WAIT -> IDLE");
    //log_display.print(line_name);
    //log_display.println(" zavesil");
    new_mode = MODE_IDLE;    
  }
  else if ((mode == MODE_MUTE) && !off_hook) {
    Serial.print(line_name);
    Serial.println(" MUTE -> IDLE");
    //log_display.print(line_name);
    //log_display.println(" zavesil");
    new_mode = MODE_IDLE;    
  }
  else if ((mode == MODE_CALL) && !off_hook) {
    Serial.print(line_name);
    Serial.println(" CALL -> IDLE");
    //log_display.print(line_name);
    //log_display.println(" zavesil");
    stopMelody();
    new_mode = MODE_IDLE;    
  }
  else if ((mode == MODE_CONNECT) && !off_hook) {
    Serial.print(line_name);
    Serial.println(" CONNECT -> IDLE");
    //log_display.print(line_name);
    //log_display.println(" zavesil");
    stopMelody();
    new_mode = MODE_IDLE;    
  }
  else if ((mode == MODE_INVALID) && !off_hook) {
    Serial.print(line_name);
    Serial.println(" INVALID -> IDLE");
    //log_display.print(line_name);
    //log_display.println(" zavesil");
    stopMelody();
    new_mode = MODE_IDLE;    
  }
  else if ((mode == MODE_BUSY) && !off_hook) {
    Serial.print(line_name);
    Serial.println(" BUSY -> IDLE");
    //log_display.print(line_name);
    //log_display.println(" zavesil");
    stopMelody();
    new_mode = MODE_IDLE;    
  }

  // -- handle conflicts!
  
  // 1) if both are to play a melody, do not allow that
  // TBD
  // 2) if one is connected and the other not, crash everything
  // TBD

  // -- scrap meaningless state change
  if (new_mode == mode) new_mode = MODE_NULL;

  //Serial.print("State update for ");
  //Serial.print(line_name);
  //Serial.println(" completed.");

  return new_mode;

}

void setNewState(lineID line, lineMode new_mode, char line_name) {
  // -- handle actual state
  if (new_mode == MODE_NULL) {
    // ok, do nothing. why would you.
  } else
  if (new_mode == MODE_IDLE) {
    Serial.print(line_name);
    Serial.println(F(" ~ IDLE"));
    set_bus(false);
  } else
  if (new_mode == MODE_MUTE) {
    Serial.print(line_name);
    Serial.println(F(" ~ MUTE"));
    set_bus(false);
  } else
  if (new_mode == MODE_DIAL) {
    Serial.print(line_name);
    Serial.println(F(" ~ DIAL"));
    set_bus(false);
    stopMelody();
  } else
  if (new_mode == MODE_WAIT) {
    Serial.print(line_name);
    Serial.println(F(" ~ WAIT"));
    set_bus(false);
    playMelody(melodyDialLength_, melodyDial_, line);
} else
  if (new_mode == MODE_CONNECT) {
    Serial.print(line_name);
    Serial.println(F(" ~ CONNECT"));
    ringCounter = -1;
    delay(1);
    set_bus(true);
  } else
  if (new_mode == MODE_RING) {
    Serial.print(line_name);
    Serial.println(F(" ~ RING"));
    set_bus(false);
    delay(1);
    // reset the counter so it starts nicely
    ringCounter = 0;
  } else
  if (new_mode == MODE_CALL) {
    Serial.print(line_name);
    Serial.println(F(" ~ CALL"));
    set_bus(false);
    playMelody(melodyCallLength_, melodyCall_, line);
  } else 
  if (new_mode == MODE_INVALID) {
    Serial.print(line_name);
    Serial.println(F(" ~ INVALID"));
    set_bus(false);
    playMelody(melodyInvalidLength_, melodyInvalid_, line);
  } else 
  if (new_mode == MODE_BUSY) {
    Serial.print(line_name);
    Serial.println(F(" ~ BUSY"));
    set_bus(false);
    playMelody(melodyBusyLength_, melodyBusy_, line);
  } else 
  {
    Serial.print(line_name);
    Serial.println(F(" ~ NO VALID STATE"));
    // invalid state !!!
    set_bus(false);
  }
}

// -- transition from DIAL either to INVALID or CALL based on the number dialed
lineMode processDial(lineID line, char line_name, char other_line_name, int other_number) {
  log_display.print(line_name);
  log_display.print(" vytocil ");
  log_display.println(dial_read);

  Serial.print(line_name);
  Serial.print(" dialled ");
  Serial.println(dial_read);
  
  if (dial_read == other_number) {
    log_display.print("Volam ");
    log_display.println(other_line_name);
    
    Serial.print("Correct number, should call ");
    Serial.println(other_line_name);
    Serial.print(line_name);
    Serial.println(" DIAL -> CALL");
    
    setNewState(line, MODE_CALL, line_name);
    return MODE_CALL;
  } else {
    log_display.println("Volane cislo neex.");
    Serial.println("Incorrect number!");
    Serial.print(line_name);
    Serial.println(" DIAL -> INVALID");

    setNewState(line, MODE_INVALID, line_name);
    return MODE_INVALID;
  }
}
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

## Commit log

2023-07-16 add pcb in pdf
2023-07-16 some basic docs. fixed tone freqs
    [melody.ino]
